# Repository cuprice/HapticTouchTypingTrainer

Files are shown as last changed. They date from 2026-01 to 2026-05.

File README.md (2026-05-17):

## タイピング練習用キーボード基板 Haptic Touch Typing Trainer (Prototype)

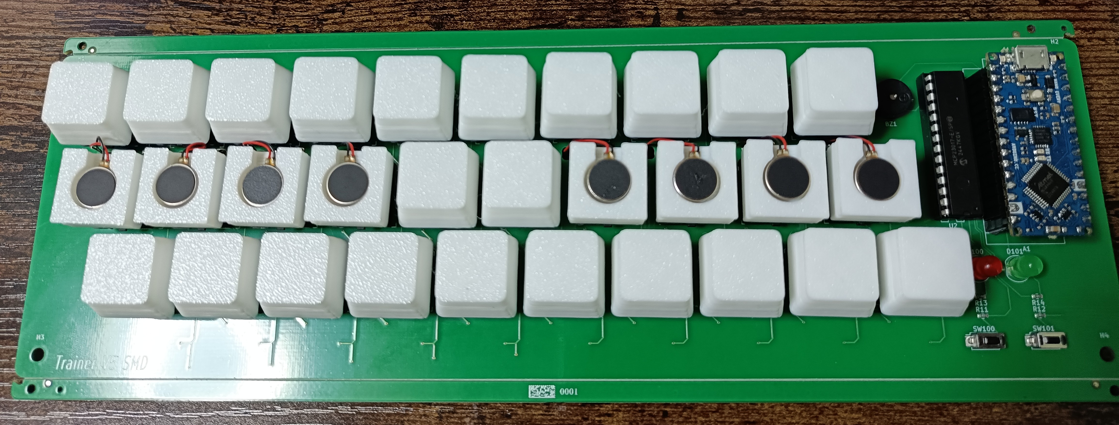
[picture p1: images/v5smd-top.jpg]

基板写真

# これは何？
What is this?

A haptic and audio-guided touch typing trainer that tells you which key to press next through vibration and sound — no need to look at your hands.

振動と音で次に押すべきキーを知らせる、触覚と聴覚を使ったタッチタイピング練習機です。

# はじめに

このリポジトリは回路・プログラミング初学者の学習用です。あたたかく見守っていただけると嬉しいです。

これは、プログラミングや回路の初心者である私が、自分なりに学びながら作ってみた実装基板です。  
8つのキーに振動する部品を付け、目で確認しなくてもどこを押せば良いかがわかる機能を目指しました。
~~公開しようと思ったきっかけは、似たようなアイデアのタイピング練習機を見つけることができなかったためです。~~

触覚を利用した複雑なタッチタイピングの練習機械が他にもあることを知り、私はまだまだ勉強不足であると思いました。もしお嫌でなければ、学習の活動を見守っていただければ幸いです。

このリポジトリでは、タイピング練習を目的としたキーボード基板の設計データを公開しています。  
基板はKiCad 9.0で設計されています。振動するキー順番を変更するには、Arduinoのスケッチを編集する必要があります。

ただし、現在はアイデア段階であり、完全な完成品ではありません。今後の改善や追加機能に関しては更新を行う予定です。

This repository is for beginners who are learning circuits and programming.
I’d be happy if you could kindly support it.

This is a keyboard I made while learning programming and circuits by myself.
I am still a beginner, but I tried my best to build it.

I added small parts that can vibrate to 8 keys.
This way, you can feel which key to press without looking.

~~I decided to share this because I couldn't find a similar typing practice device online.~~

I learned that there are other machines that use touch to practice touch typing in a complex way, and I felt that I still have a lot to learn.
If you don’t mind, I would be happy if you could watch over my learning.

In this repository, I show the design data for this keyboard.
I made the design using KiCad 9.0.
If you want to change the order of the vibrating keys, you need to change the Arduino program.

Please note that this is still just an idea, not a finished product.
I want to improve it and add more features in the future.

---

## 特徴

- 10列、3段のキー(計30個)による練習用構成
- リセットスイッチ付き
- Cherry MX対応
- Arduino Nano Everyで完璧ではありませんが、一応動作確認済みです (後継機のモデルは動作未確認)
- KiCad 9.0で基板設計
- 基板サイズ：約261.1mm × 81.5mm(捨て基板除く)
- 電源：Arduino Nano Every経由でのUSB給電

This is a practice keyboard layout with 30 keys, arranged in 10 columns and 3 rows.
It includes a reset switch. It's compatible with Cherry MX switches. I've confirmed it works with the Arduino nano every, although it's not perfect. I haven't tested it with newer Arduino models. The circuit board was designed using KiCad 9.0. The board size is about 261.1mm × 81.5mm, and it's powered by USB through the Arduino nano every.

どの段のキーを押せば良いかを、3段階のブザー音で教えるためのコードを加筆修正しました。上の段ならば3回鳴り、下の段ならば１回鳴り、真ん中の段なら２回鳴るという仕組みにしました。振動モーターがないキーの場合は、振動する長さを変えて位置を知らせるようにしました。

I changed the code to use three kinds of buzzer sounds to tell the user which row of keys to press.
If the key is on the top row, the buzzer beeps three times.
If the key is on the bottom row, it beeps one time.
If the key is on the middle row, it beeps two times.
For keys that do not have a vibration motor, the device changes the length of the vibration to show the position.

---

## ファイル構成

~~~

TypingTrainer/
    ├── TYPING-TRAINER-V5-SMD/ # KiCad設計ファイル
    ├── TYPING-TRAINER-V5-SMD.zip # ガーバーデータ（基板製造用）
    ├── TrainerV5-smd/ # Arduinoスケッチ 通常版
    ├── TrainerV5-smd2/ # Arduinoスケッチ 切替式例文プリセットタイプ
    ├── numorder.py # キーの順番を決めるPythonスクリプト
    ├── keycap.stl # 3Dプリンタ用、穴有りキャップ
    ├── images/ # 写真・完成図
    ├── docs/ # 部品表・座標データなど
    ├── OldVersion-Uno # 旧バージョン、Uno用
    ├── OldVersion-Nano # 旧バージョン、Nano用
    └── README.md # このファイル

~~~

---

## 完成イメージ、回路図、動作の様子

基板写真

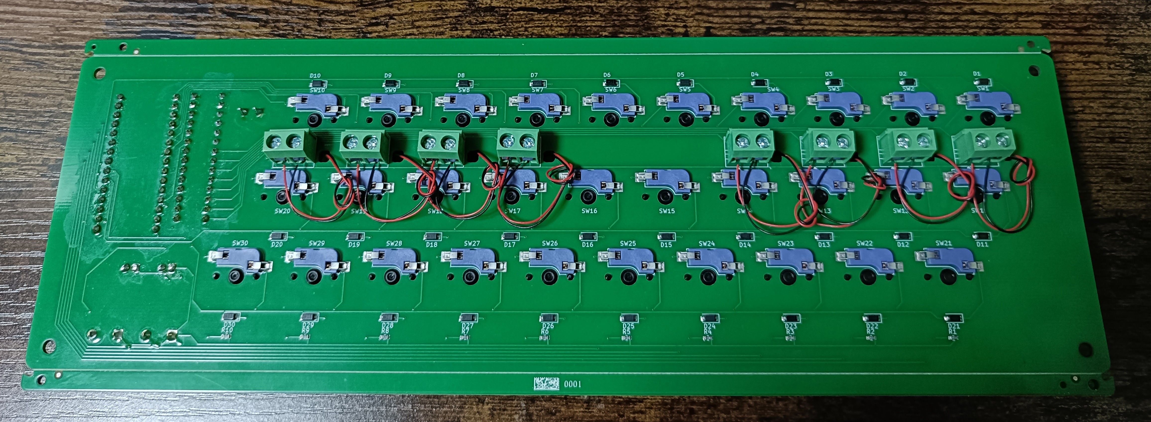
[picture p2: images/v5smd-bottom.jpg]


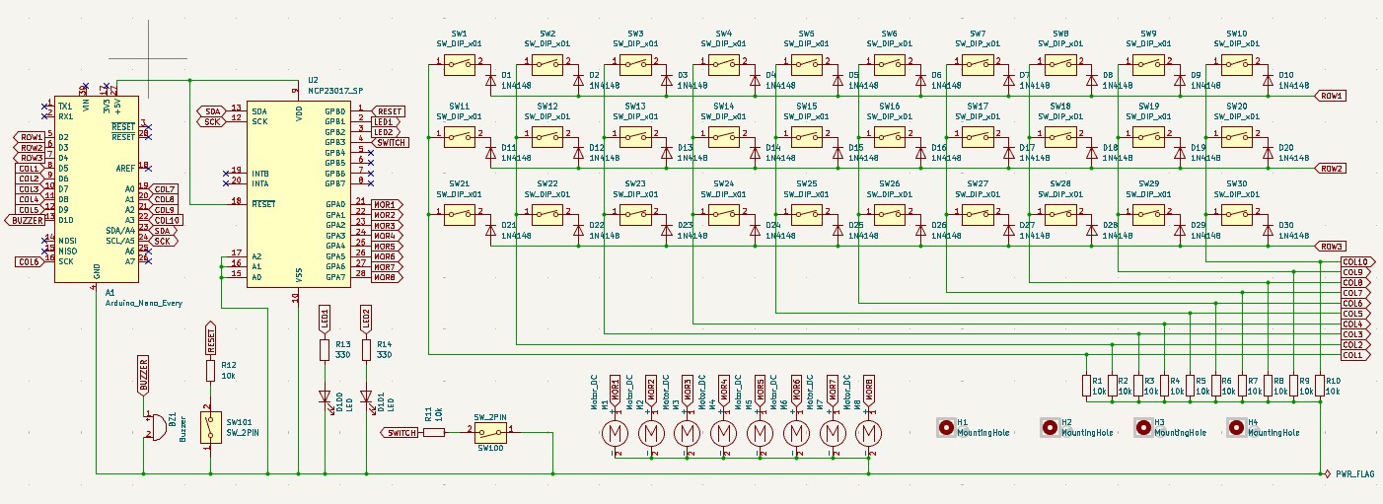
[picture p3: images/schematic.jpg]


[動作の様子](images/working.mp4)

[モーターの動き](images/shaker.mp4)

---

## 使い方
1. ガーバーファイルをJLCPCBなどで製造依頼
2. 回路図などを見ながら部品を実装
3. Arduino Nano EveryをUSBケーブルでPCと接続
4. PCからArduinoへ、ファームウェアを書き込み

---

## 必要部品

| Value | Reference | Qty | 備考 | 画像 |
|---|---|-----|---|---|
| Arduino Nano Every  | A1 | 1 | マイクロコントローラー（ソケットピン経由で実装） |  |
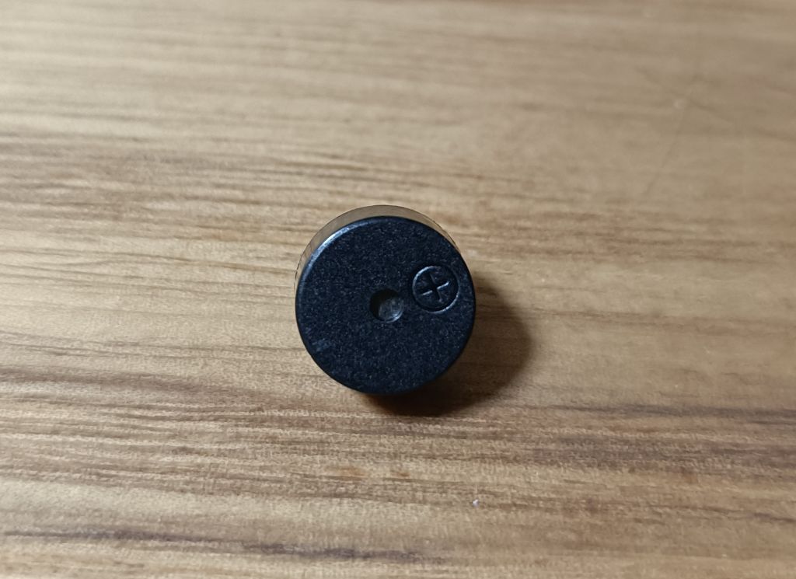
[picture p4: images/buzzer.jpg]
| Passive Buzzer | BZ1 | 1 | パッシブブザー |  |
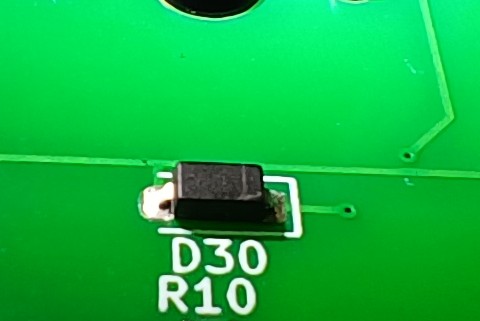
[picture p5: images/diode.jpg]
| 1N4148 | D1 〜 D30 | 30  | スイッチのマトリックス用ダイオード |  |
| LED | D100, D101 | 2 | インジケーターLED |  |
| Motor DC | M1 〜 M8 | 8 | DCモーター |  |
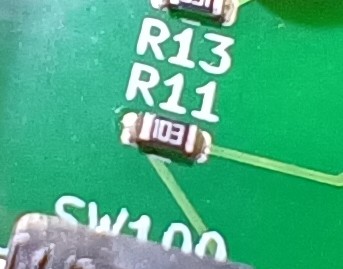
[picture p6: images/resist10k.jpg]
| Resist 10k | R1 〜 R12 | 12  | 抵抗（10kΩ） |  |
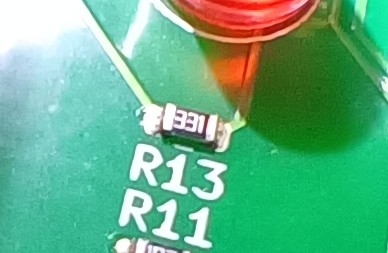
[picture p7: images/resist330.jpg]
| Resist 330 | R13, R14 | 2 | 抵抗（330Ω, LED電流制限用） |  |
| Cherry MX Switch | SW1 〜 SW30 | 30  | Cherry MX互換キースイッチ(キーキャップはお好みで) |  |
| 2pin Button | SW100, SW101 | 2 | 2ピンのタクトスイッチなど |  |
| MCP23017_SP | U2 | 1 | I/Oエキスパンダー（ICソケットの上に実装） |  |
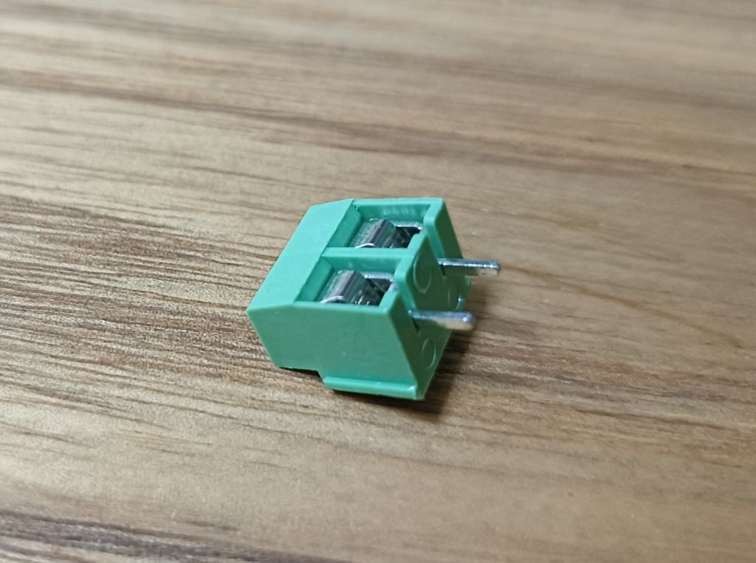
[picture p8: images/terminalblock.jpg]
| TerminalBlock | M1 〜 M8 | 8 | ターミナルブロック(裏面実装) |  |
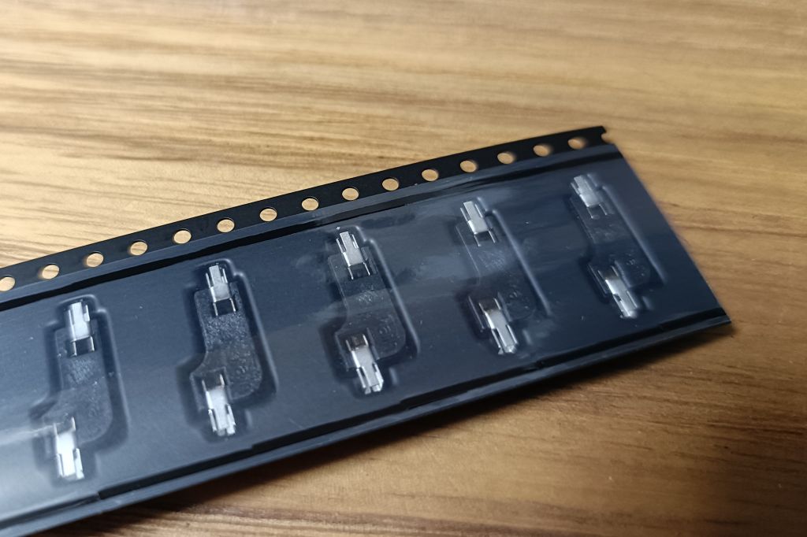
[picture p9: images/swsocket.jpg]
| SW socket | SW1 〜 SW30 | 30 | キースイッチソケット(裏面実装) |  |

---

## KiCad情報

- KiCad バージョン: 9.0
- 古いバージョンでは一部ファイルが開けない可能性があります。
- 最新バージョンでの動作は未確認です。

使用したライブラリURL
- ブザーフットプリント
 https://jp.sameskydevices.com/product/resource/pcbfootprint/cmt-9648-85t
- キースイッチフットプリント
 https://github.com/daprice/keyswitches.pretty?tab=readme-ov-file

---

## ライセンス

この基板デザインは MIT ライセンスで公開しています。  

---

## よくある質問

準備中
**Q. ？**  
A. 

---

## 注意事項

- 初心者が学びながら作ったものなので、不完全な点もあるかもしれません。
- Arduinoスケッチの一部のコード作成に、生成AI（ChatGPT）を補助的に活用しました。

---

## Special Thanks

- ネット上のチュートリアルや電子工作記事の皆さま

---

# 今後の予定
- キーを押す順番の配列を簡単に作るツール
- 製作手順のガイドを作る

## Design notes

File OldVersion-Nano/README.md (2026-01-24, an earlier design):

## タイピング練習用キーボード基板 Typing Haptic Trainer (Prototype)

基板写真
キーキャップ

2026.1.24
3Dプリンターを購入して、試しに特定のキーだけキーキャップをはめ込み式に変えました。あと、この先の予定としては、ダイオードや抵抗を表面実装に変更したものを作るつもりです。

I bought a 3D printer and tried changing only some keycaps to a snap-on type.
Next, I plan to make a version with surface-mounted diodes and resistors.

2025.11.25
Githubに公開してから数ヶ月経ちました。それ以来、触覚を利用したタッチタイピングの練習機械が他にもあることを知り、私のウェブ検索が十分でなかったと申し訳なく思いました。他の人々の作る機械はとても複雑でレベルの高いことも知り、私はまだまだ勉強不足であると思いました。もしお嫌でなければ、学習の活動を見守っていただければ幸いです。

I published my project on GitHub a few months ago.
After that, I learned that there are other typing training devices that use touch.
I felt sorry because my web search was not good enough.
I also found that other people’s devices are very complex and high-level, and I realized that I still have a lot to learn. If you don’t mind, I would be happy if you could watch my learning journey.

2025.11.23
基板を新しくしました！作った基板にArduino Nano Everyを組み込みました。
I made a new PCB and installed an Arduino Nano Every on it.

このリポジトリは回路・プログラミング初学者の学習用です。あたたかく見守っていただけると嬉しいです。

これは、プログラミングや回路の初心者である私が、自分なりに学びながら作ってみた実装基板です。  
8つのキーに振動する部品を付け、目で確認しなくてもどこを押せば良いかがわかる機能を目指しました。
公開しようと思ったきっかけは、似たようなアイデアのタイピング練習機を見つけることができなかったためです。

このリポジトリでは、タイピング練習を目的としたキーボード基板の設計データを公開しています。  
基板はKiCad 9.0で設計されています。振動するキー順番を変更するには、Arduinoのスケッチを編集する必要があります。

ただし、現在はアイデア段階であり、完全な完成品ではありません。今後の改善や追加機能に関しては更新を行う予定です。

This repository is for beginners who are learning circuits and programming.
I’d be happy if you could kindly support it.

This is a keyboard I made while learning programming and circuits by myself.
I am still a beginner, but I tried my best to build it.

I added small parts that can vibrate to 8 keys.
This way, you can feel which key to press without looking.

I decided to share this because I couldn't find a similar typing practice device online.

In this repository, I show the design data for this keyboard.
I made the design using KiCad 9.0.
If you want to change the order of the vibrating keys, you need to change the Arduino program.

Please note that this is still just an idea, not a finished product.
I want to improve it and add more features in the future.

---

## 特徴

- 10列、3段のキー(計30個)による練習用構成
- リセットスイッチ付き
- Cherry MX対応
- Arduino nano everyで完璧ではありませんが、一応動作確認済みです (後継機のモデルは動作未確認)
- KiCad 9.0で基板設計
- 基板サイズ：約261.1mm × 81.5mm
- 電源：Arduino nano every経由でのUSB給電

This is a practice keyboard layout with 30 keys, arranged in 10 columns and 3 rows.
It includes a reset switch. It's compatible with Cherry MX switches. I've confirmed it works with the Arduino nano every, although it's not perfect. I haven't tested it with newer Arduino models. The circuit board was designed using KiCad 9.0. The board size is about 261.1mm × 81.5mm, and it's powered by USB through the Arduino nano every.

どの段のキーを押せば良いかを、3段階のブザー音で教えるためのコードを加筆修正しました。上の段ならば3回鳴り、下の段ならば１回鳴り、真ん中の段なら２回鳴るという仕組みにしました。振動モーターがないキーの場合は、振動する長さを変えて位置を知らせるようにしました。

I changed the code to use three kinds of buzzer sounds to tell the user which row of keys to press.
If the key is on the top row, the buzzer beeps three times.
If the key is on the bottom row, it beeps one time.
If the key is on the middle row, it beeps two times.
For keys that do not have a vibration motor, the device changes the length of the vibration to show the position.

---

## ファイル構成

~~~

TypingTrainer/
    ├── TYPING-TRAINER-V5-2025-10-13_115341/ # KiCad設計ファイル
    ├── TYPING-TRAINER-V5.1.zip # ガーバーデータ（基板製造用）
    ├── TrainerV5active/ # Arduinoスケッチ
    ├── images/ # 写真・完成図
    ├── docs/ # 部品表
    └── README.md # このファイル

~~~

---

## 完成イメージ、回路図、動作の様子

基板写真

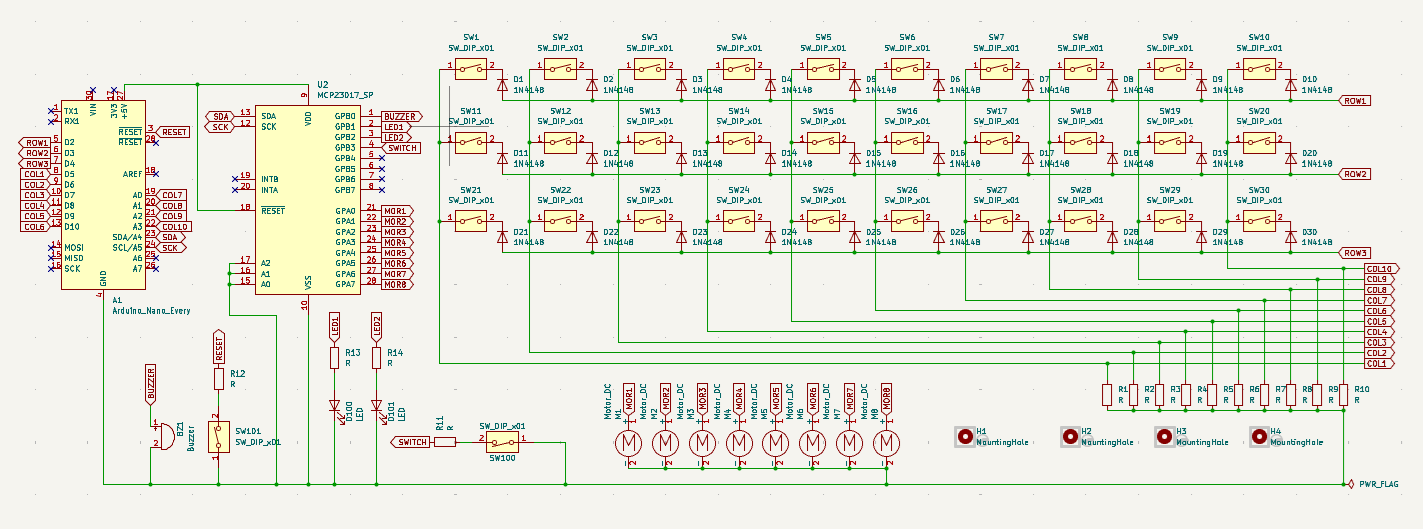
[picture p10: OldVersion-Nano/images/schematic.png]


[動作の様子](images/working.mp4)

[モーターの動き](images/shaker.mp4)

---

## 使い方
1. ガーバーファイルをPCBwayなどで製造依頼
2. 回路図などを見ながら部品を実装
3. Arduino nano everyをUSBケーブルでPCと接続
4. PCからArduinoへ、ファームウェアを書き込み

---

## 必要部品

| Value | Reference | Qty | 備考 | 画像 |
|---|---|-----|---|---|
| Arduino Nano Every  | A1 | 1 | マイクロコントローラー（ソケットピン経由で実装） |  |
| Buzzer | BZ1 | 1 | ブザー |  |
| 1N4148 | D1 〜 D30 | 30  | スイッチのマトリックス用ダイオード |  |
| LED | D100, D101 | 2 | インジケーターLED |  |
| Motor DC | M1 〜 M8 | 8 | DCモーター |  |
| 10k | R1 〜 R12 | 12  | 抵抗（10kΩ） |  |
| 330 | R13, R14 | 2 | 抵抗（330Ω, LED電流制限用） |  |
| Cherry MX Switch | SW1 〜 SW30 | 30  | Cherry MX互換キースイッチ(キーキャップはお好みで) |  |
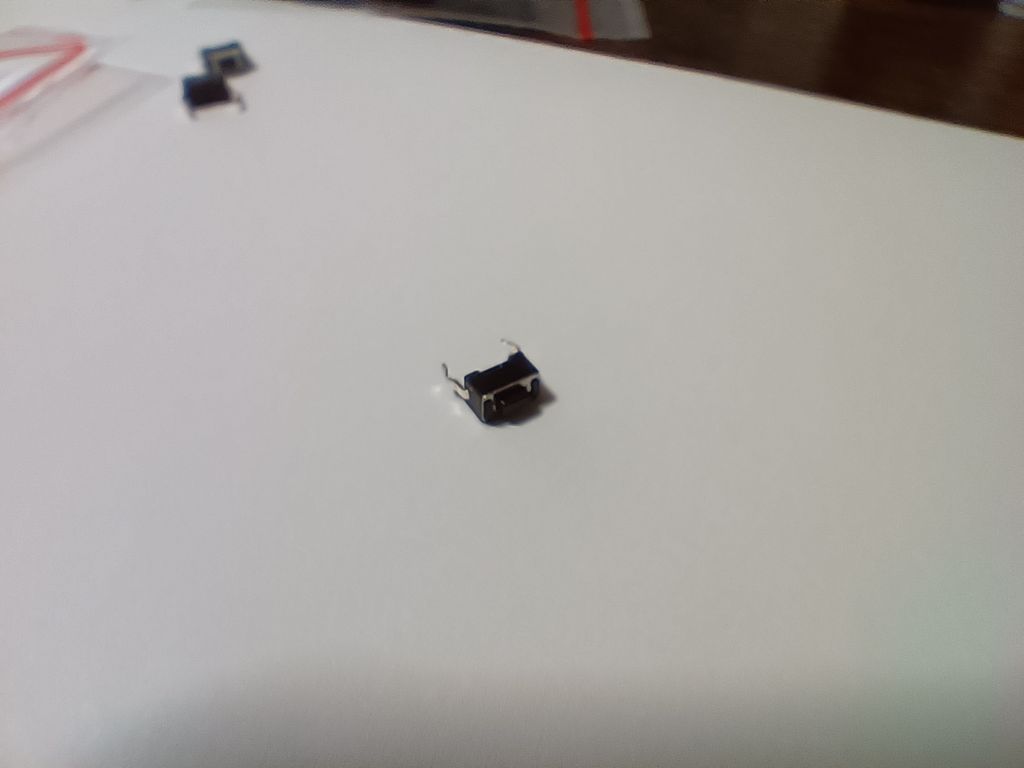
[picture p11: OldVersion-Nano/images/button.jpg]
| 2pin Button | SW100, SW101 | 2 | 2ピンのタクトスイッチなど |  |
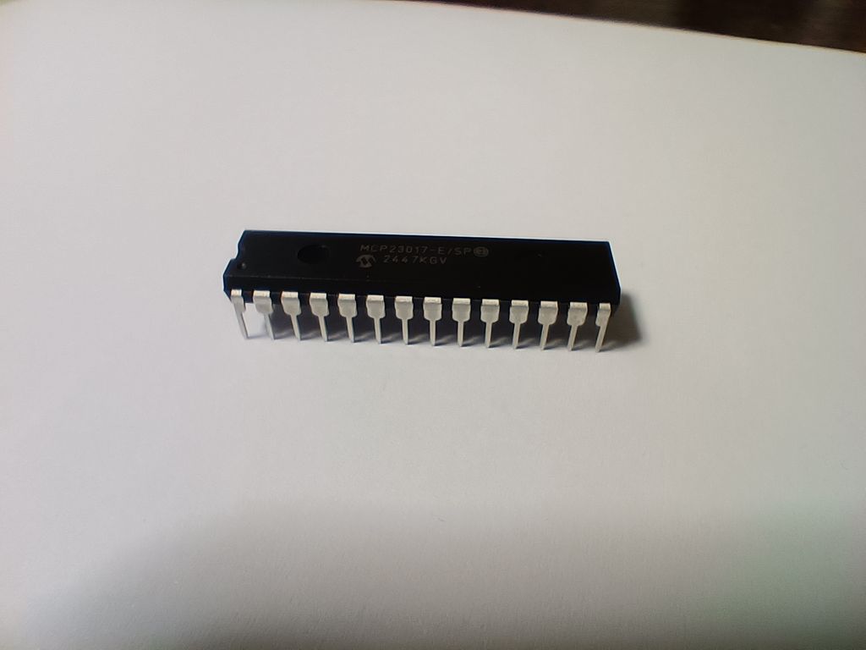
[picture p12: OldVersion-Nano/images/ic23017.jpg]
| MCP23017_SP | U2 | 1 | I/Oエキスパンダー（ICソケットの上に実装） |  |

---

## KiCad情報

- KiCad バージョン: 9.0
- 古いバージョンでは一部ファイルが開けない可能性があります。
- 最新バージョンでの動作は未確認です。

---

## ライセンス

この基板デザインは MIT ライセンスで公開しています。  

---

## よくある質問

準備中
**Q. ？**  
A. 

---

## 注意事項

- 初心者が学びながら作ったものなので、不完全な点もあるかもしれません。
- Arduinoスケッチの一部のコード作成に、生成AI（ChatGPT）を補助的に活用しました。

---

## Special Thanks

- ネット上のチュートリアルや電子工作記事の皆さま

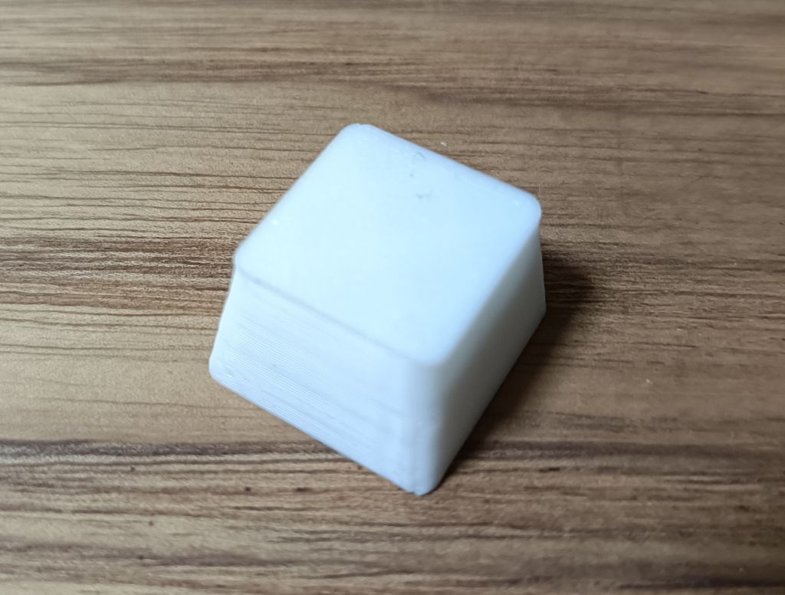
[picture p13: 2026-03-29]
images/keycap.jpg

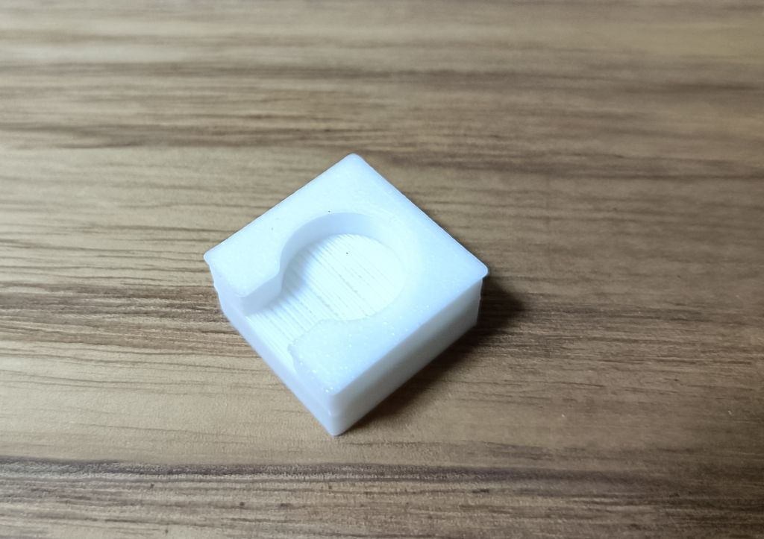
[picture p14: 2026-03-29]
images/keycap-holetype.jpg

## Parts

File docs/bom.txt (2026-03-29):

Value	                Reference	Qty	備考
Arduino Nano Every	A1	        1	マイクロコントローラー
Buzzer	                BZ1	        1	ブザー
1N4148	                D1 〜 D30	30	スイッチのマトリックス用ダイオード
LED	                D100, D101	2	インジケーターLED
TerminalBlock       M1 〜 M8	8	ターミナルブロック5mmピッチ
Motor               M1 〜 M8    8   DCDCモーター
10k	                R1 〜 R12	12	抵抗 (10kΩ)
330	                R13, R14	2	抵抗 (330Ω, LED電流制限用)
Cherry mx switch	SW1 〜 SW30	30	Cherry MX互換キースイッチ
Switch Socket   	SW1 〜 SW30	30	Cherry MX互換キーソケット
2pin button	        SW100, SW101	2	2ピンのタクトスイッチなど
MCP23017_SP	        U2	        1	I/Oエキスパンダー

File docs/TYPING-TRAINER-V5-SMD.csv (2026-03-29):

Reference | Value | Footprint | Qty | LCSC
D1,D2,D3,D4,D5,D6,D7,D8,D9,D10,D11,D12,D13,D14,D15,D16,D17,D18,D19,D20,D21,D22,D23,D24,D25,D26,D27,D28,D29,D30 | 1N4148 | Diode_SMD:D_SOD-123 | 30 | C2099
R1,R2,R3,R4,R5,R6,R7,R8,R9,R10,R11,R12 | 10k | Resistor_SMD:R_0603_1608Metric | 12 | C99198
R13,R14 | 330 | Resistor_SMD:R_0603_1608Metric | 2 | C105879
SW1,SW2,SW3,SW4,SW5,SW6,SW7,SW8,SW9,SW10,SW11,SW12,SW13,SW14,SW15,SW16,SW17,SW18,SW19,SW20,SW21,SW22,SW23,SW24,SW25,SW26,SW27,SW28,SW29,SW30 | SW_DIP_x01 | Kailh_socket_MX | 30 | C41430893

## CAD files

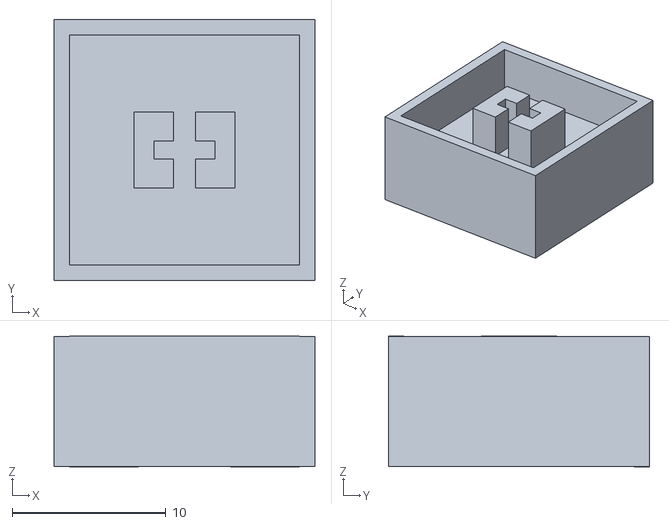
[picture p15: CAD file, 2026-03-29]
keycap.stl
17.0 x 17.0 x 8.50

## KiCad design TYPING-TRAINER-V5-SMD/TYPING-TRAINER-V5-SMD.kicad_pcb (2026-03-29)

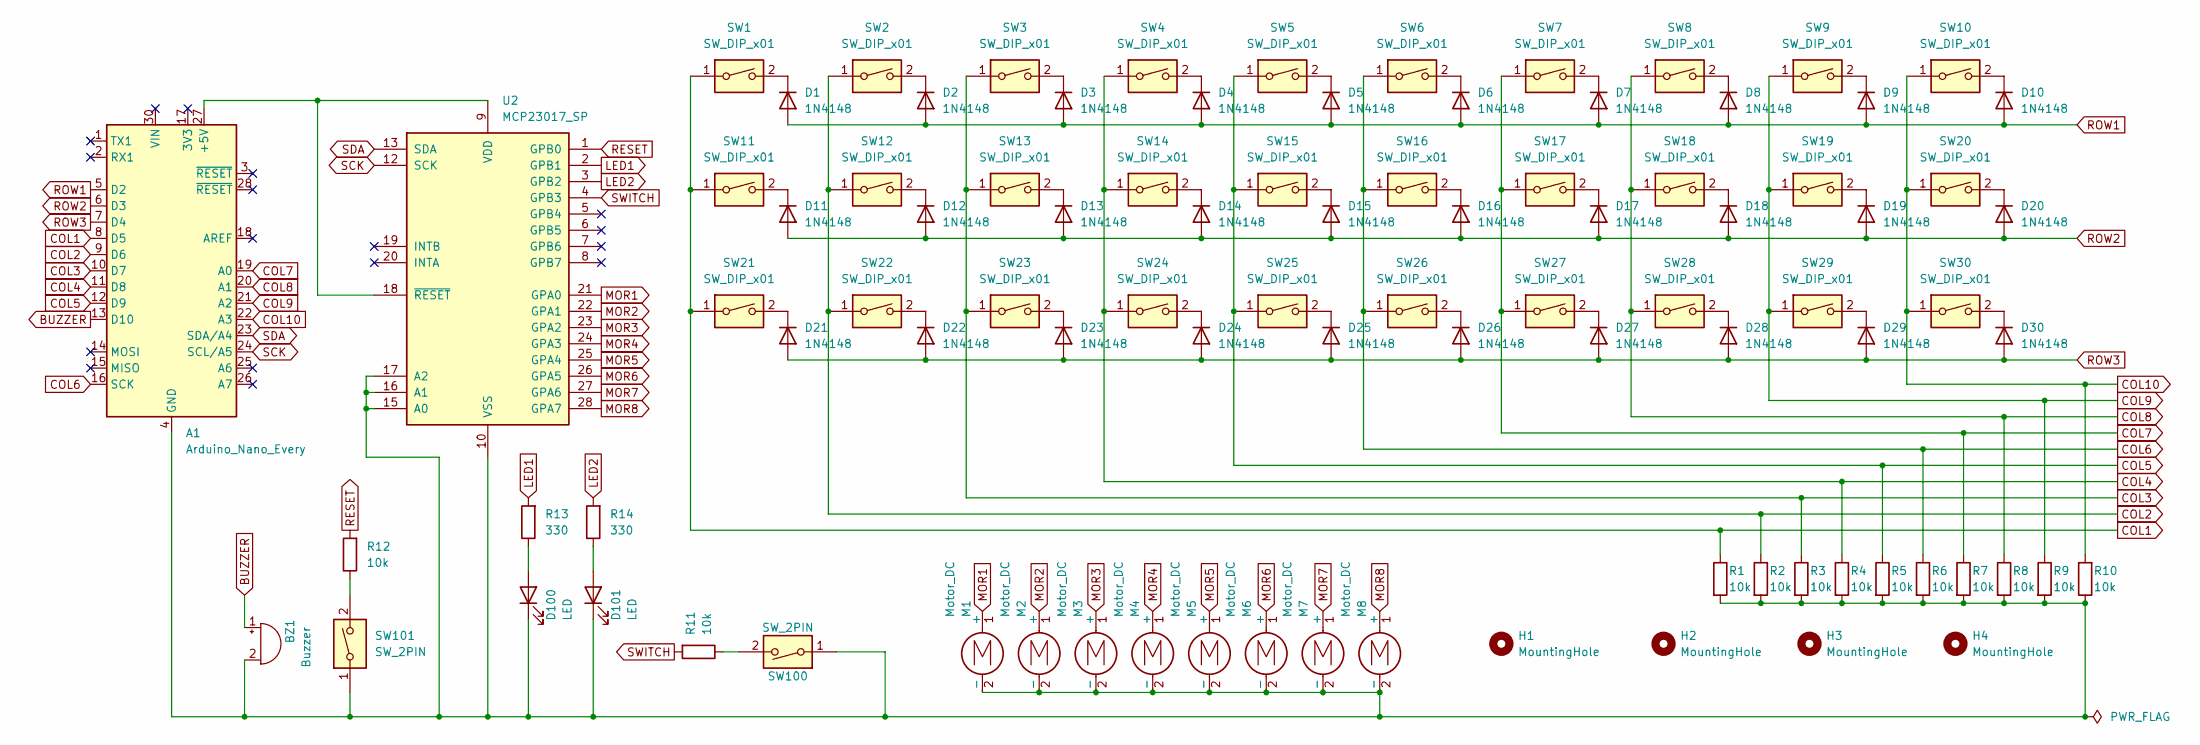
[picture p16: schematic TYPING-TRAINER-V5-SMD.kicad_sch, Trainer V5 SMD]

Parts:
A1: Arduino_Nano_Every; Arduino_Nano
BZ1: Buzzer; XDCR_CMT-9648-85T; LCSC C22359749
D1, D2, D3, D4, D5, D6, D7, D8, D9, D10, D11, D12, D13, D14, D15, D16, D17, D18, D19, D20, D21, D22, D23, D24, D25, D26, D27, D28, D29, D30: 1N4148; D_SOD-123; LCSC C2099
D100, D101: LED; LED_D5.0mm_FlatTop; LCSC C88163
H1, H2, H3, H4: MountingHole; MountingHole_3.2mm_M3
M1, M2, M3, M4, M5, M6, M7, M8: Motor_DC; TerminalBlock_MaiXu_MX126-5.0-02P_1x02_P5.00mm
R1, R2, R3, R4, R5, R6, R7, R8, R9, R10, R11, R12: 10k; R_0603_1608Metric; LCSC C130232
R13, R14: 330; R_0603_1608Metric; LCSC C175652
SW1, SW2, SW3, SW4, SW5, SW6, SW7, SW8, SW9, SW10, SW11, SW12, SW13, SW14, SW15, SW16, SW17, SW18, SW19, SW20, SW21, SW22, SW23, SW24, SW25, SW26, SW27, SW28, SW29, SW30: SW_DIP_x01; Kailh_socket_MX; LCSC C41430893
SW100, SW101: SW_2PIN; SW_PUSH_1P1T_6x3.5mm_H4.3_APEM_MJTP1243
U2: MCP23017_SP; DIP-28_W7.62mm

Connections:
BUZZER: A1.13 (D10), BZ1.1 (+)
COL1: A1.8 (D5), R1.1, SW1.1, SW11.1, SW21.1
COL2: A1.9 (D6), R2.1, SW2.1, SW12.1, SW22.1
COL3: A1.10 (D7), R3.1, SW3.1, SW13.1, SW23.1
COL4: A1.11 (D8), R4.1, SW4.1, SW14.1, SW24.1
COL5: A1.12 (D9), R5.1, SW5.1, SW15.1, SW25.1
COL6: A1.16 (SCK), R6.1, SW6.1, SW16.1, SW26.1
COL7: A1.19 (A0), R7.1, SW7.1, SW17.1, SW27.1
COL8: A1.20 (A1), R8.1, SW8.1, SW18.1, SW28.1
COL9: A1.21 (A2), R9.1, SW9.1, SW19.1, SW29.1
COL10: A1.22 (A3), R10.2, SW10.1, SW20.1, SW30.1
LED1: R13.2, U2.2 (GPB1)
LED2: R14.2, U2.3 (GPB2)
MOR1: M1.1 (+), U2.21 (GPA0)
MOR2: M2.1 (+), U2.22 (GPA1)
MOR3: M3.1 (+), U2.23 (GPA2)
MOR4: M4.1 (+), U2.24 (GPA3)
MOR5: M5.1 (+), U2.25 (GPA4)
MOR6: M6.1 (+), U2.26 (GPA5)
MOR7: M7.1 (+), U2.27 (GPA6)
MOR8: M8.1 (+), U2.28 (GPA7)
unnamed: A1.27 (+5V), U2.9 (VDD), U2.18 (~RESET)
unnamed: A1.4 (GND), A1.29 (GND), BZ1.2 (-), D100.1 (K), D101.1 (K), M1.2 (-), M2.2 (-), M3.2 (-), M4.2 (-), M5.2 (-), M6.2 (-), M7.2 (-), M8.2 (-), R1.2, R2.2, R3.2, R4.2, R5.2, R6.2, R7.2, R8.2, R9.2, R10.1, SW100.1, SW101.1, U2.10 (VSS), U2.15 (A0), U2.16 (A1), U2.17 (A2)
unnamed: D1.1 (K), SW1.2
unnamed: D2.1 (K), SW2.2
unnamed: D3.1 (K), SW3.2
unnamed: D4.1 (K), SW4.2
unnamed: D5.1 (K), SW5.2
unnamed: D6.1 (K), SW6.2
unnamed: D7.1 (K), SW7.2
unnamed: D8.1 (K), SW8.2
unnamed: D9.1 (K), SW9.2
unnamed: D10.1 (K), SW10.2
unnamed: D11.1 (K), SW11.2
unnamed: D12.1 (K), SW12.2
unnamed: D13.1 (K), SW13.2
unnamed: D14.1 (K), SW14.2
unnamed: D15.1 (K), SW15.2
unnamed: D16.1 (K), SW16.2
unnamed: D17.1 (K), SW17.2
unnamed: D18.1 (K), SW18.2
unnamed: D19.1 (K), SW19.2
unnamed: D20.1 (K), SW20.2
unnamed: D21.1 (K), SW21.2
unnamed: D22.1 (K), SW22.2
unnamed: D23.1 (K), SW23.2
unnamed: D24.1 (K), SW24.2
unnamed: D25.1 (K), SW25.2
unnamed: D26.1 (K), SW26.2
unnamed: D27.1 (K), SW27.2
unnamed: D28.1 (K), SW28.2
unnamed: D29.1 (K), SW29.2
unnamed: D30.1 (K), SW30.2
unnamed: D100.2 (A), R13.1
unnamed: D101.2 (A), R14.1
unnamed: R11.1, SW100.2
unnamed: R12.1, SW101.2
RESET: R12.2, U2.1 (GPB0)
ROW1: A1.5 (D2), D1.2 (A), D2.2 (A), D3.2 (A), D4.2 (A), D5.2 (A), D6.2 (A), D7.2 (A), D8.2 (A), D9.2 (A), D10.2 (A)
ROW2: A1.6 (D3), D11.2 (A), D12.2 (A), D13.2 (A), D14.2 (A), D15.2 (A), D16.2 (A), D17.2 (A), D18.2 (A), D19.2 (A), D20.2 (A)
ROW3: A1.7 (D4), D21.2 (A), D22.2 (A), D23.2 (A), D24.2 (A), D25.2 (A), D26.2 (A), D27.2 (A), D28.2 (A), D29.2 (A), D30.2 (A)
SCK: A1.24 (SCL/A5), U2.12 (SCK)
SDA: A1.23 (SDA/A4), U2.13 (SDA)
SWITCH: R11.2, U2.4 (GPB3)

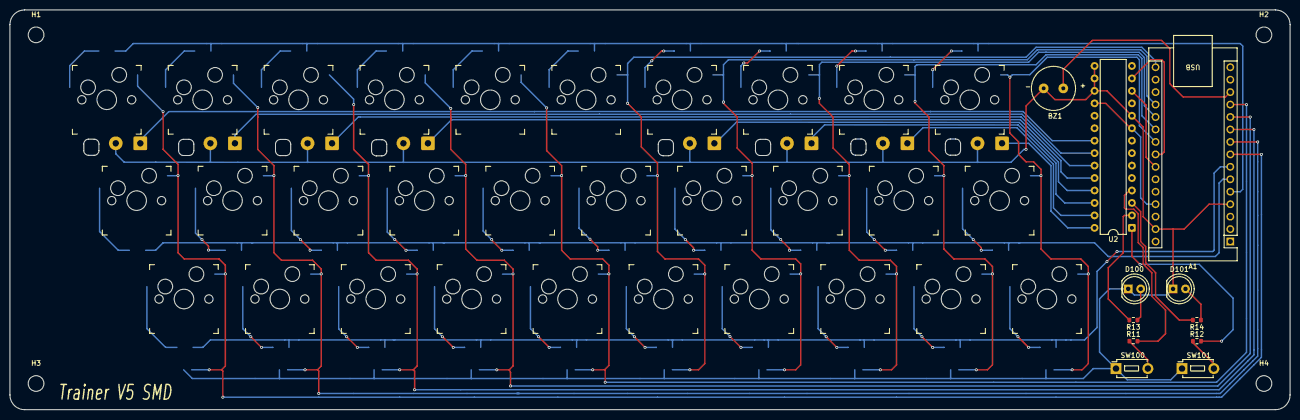
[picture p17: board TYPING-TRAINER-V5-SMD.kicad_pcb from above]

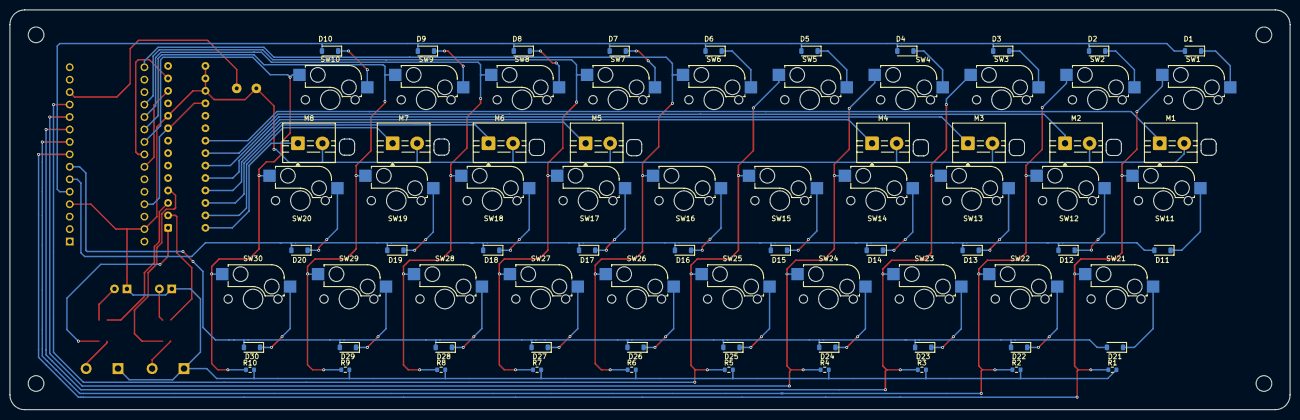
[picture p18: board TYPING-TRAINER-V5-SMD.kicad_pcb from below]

Board: 2 copper layers, 261.1 x 81.5 mm, 93 parts (48 on the bottom side), 64 nets.

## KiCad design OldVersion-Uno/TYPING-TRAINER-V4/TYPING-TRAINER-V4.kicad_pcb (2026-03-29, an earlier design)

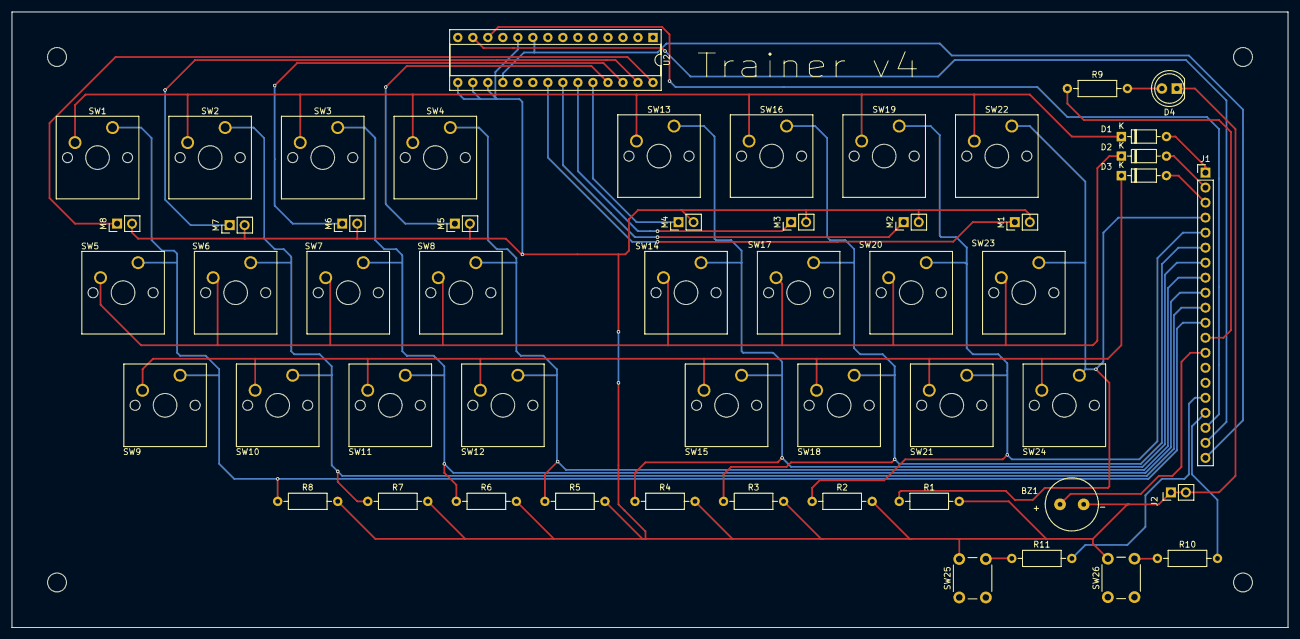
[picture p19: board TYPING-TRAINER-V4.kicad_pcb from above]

Board: 2 copper layers, 215.9 x 104.1 mm, 57 parts (0 on the bottom side), 33 nets.

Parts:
BZ1: Buzzer; XDCR_CMT-9648-85T
D1, D2, D3: 1N4148; D_DO-35_SOD27_P7.62mm_Horizontal
D4: LED; LED_D5.0mm_FlatTop
H1, H2, H3, H4: MountingHole; MountingHole_3.2mm_M3
J1: Conn_01x20_Pin; PinHeader_1x20_P2.54mm_Vertical
J2: Conn_01x02_Pin; PinHeader_1x02_P2.54mm_Vertical
M1, M2, M3, M4, M5, M6, M7, M8: Motor_DC; PinHeader_1x02_P2.54mm_Vertical
R1, R2, R3, R4, R5, R6, R7, R8, R9, R10, R11: R; R_Axial_DIN0207_L6.3mm_D2.5mm_P10.16mm_Horizontal
SW1, SW2, SW3, SW4, SW5, SW6, SW7, SW8, SW9, SW10, SW11, SW12, SW13, SW14, SW15, SW16, SW17, SW18, SW19, SW20, SW21, SW22, SW23, SW24: SW_DIP_x01; SW_Cherry_MX_1.00u_PCB
SW25, SW26: SW_DIP_x02b; SW_PUSH_6mm
U2: MCP23017_SP; CERDIP-28_W7.62mm_SideBrazed_Socket

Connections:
+5V: J1.20, U2.9 (VDD), U2.18 (~RESET)
GND: BZ1.2 (-), D4.1 (K), J2.1, J2.2, M1.2 (-), M2.2 (-), M3.2 (-), M4.2 (-), M5.2 (-), M6.2 (-), M7.2 (-), M8.2 (-), R1.2, R2.2, R3.2, R4.2, R5.2, R6.2, R7.2, R8.2, SW25.1, SW26.1, U2.10 (VSS), U2.15 (A0), U2.16 (A1), U2.17 (A2)
unnamed: BZ1.1 (+), J1.13
unnamed: D1.2 (A), J1.1
unnamed: D1.1 (K), SW1.2, SW2.2, SW3.2, SW4.2, SW13.2, SW16.2, SW19.2, SW22.2
unnamed: D2.2 (A), J1.2
unnamed: D2.1 (K), SW5.2, SW6.2, SW7.2, SW8.2, SW14.2, SW17.2, SW20.2, SW23.2
unnamed: D3.2 (A), J1.3
unnamed: D3.1 (K), SW9.2, SW10.2, SW11.2, SW12.2, SW15.2, SW18.2, SW21.2, SW24.2
unnamed: D4.2 (A), R9.2
unnamed: J1.4, R1.1, SW22.1, SW23.1, SW24.1
unnamed: J1.5, R2.1, SW19.1, SW20.1, SW21.1
unnamed: J1.6, R3.1, SW16.1, SW17.1, SW18.1
unnamed: J1.7, R4.1, SW13.1, SW14.1, SW15.1
unnamed: J1.8, R5.1, SW4.1, SW8.1, SW12.1
unnamed: J1.9, R6.1, SW3.1, SW7.1, SW11.1
unnamed: J1.10, R7.1, SW2.1, SW6.1, SW10.1
unnamed: J1.11, R8.1, SW1.1, SW5.1, SW9.1
unnamed: J1.12, R9.1
unnamed: J1.16, R11.2
unnamed: J1.17, R10.2
unnamed: J1.18, U2.12 (SCK)
unnamed: J1.19, U2.13 (SDA)
unnamed: M1.1 (+), U2.21 (GPA0)
unnamed: M2.1 (+), U2.22 (GPA1)
unnamed: M3.1 (+), U2.23 (GPA2)
unnamed: M4.1 (+), U2.24 (GPA3)
unnamed: M5.1 (+), U2.25 (GPA4)
unnamed: M6.1 (+), U2.26 (GPA5)
unnamed: M7.1 (+), U2.27 (GPA6)
unnamed: M8.1 (+), U2.28 (GPA7)
unnamed: R10.1, SW26.2
unnamed: R11.1, SW25.2

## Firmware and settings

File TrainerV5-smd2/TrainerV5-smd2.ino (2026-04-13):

#include <Adafruit_MCP23X17.h>

Adafruit_MCP23X17 mcp;

const int ROWS = 3;
const int COLS = 10;
const int resetPin = 8;

const int rowPins[ROWS] = {2, 3, 4};
const int colPins[COLS] = {5, 6, 7, 8, 9, 13, 14, 15, 16, 17};

int motorPins[8] = {0, 1, 2, 3, 4, 5, 6, 7};

// ブザー
const int buzzerPin = 10;
const int led = 9;

// ===== タイプ切り替えスイッチ（GPB3）=====
const int typeSwitchPin = 11;
bool lastSwitchState = HIGH;

// ===== 音階 =====
#define DO 262
#define MI 330
#define SO 392
#define LOW_BUZZ 130

// ===== 4タイプ配列 =====
// 赤坂の朝日が坂を上がる光を探す
int motorOrder1[] = {
    0,7,0,1,0,7,0,5,8,0,1,0,5,7,4,0,1,0,7,0,1,8,0,4,0,3,6,5,7,7,0,3,7,1,8,1,0,4,0,1,6
};

int keyRowOrder1[] = {
    1,1,1,1,1,1,1,2,0,1,1,1,1,0,1,1,1,1,1,1,0,0,1,1,1,0,0,1,0,1,1,0,0,0,0,1,1,1,1,1,0
};

// 朝日が差す公園で子どもたちが遊ぶ
int motorOrder2[] = {
    0,1,0,5,7,4,0,1,0,1,6,7,8,6,2,5,2,2,7,8,2,8,6,8,4,0,4,7,4,0,0,1,8,4,6
};

int keyRowOrder2[] = {
    1,1,1,1,0,1,1,1,1,1,0,1,0,0,0,2,1,0,1,0,1,0,2,0,0,1,0,0,1,1,1,1,0,2,0
};

// 魚が川を泳ぎながら水の中で遊ぶ
int motorOrder3[] = {
    1,0,7,0,5,0,4,0,7,0,1,0,1,8,8,5,8,4,7,5,0,4,0,3,0,6,7,0,6,5,8,5,0,7,0,2,2,0,1,8,4,6
};

int keyRowOrder3[] = {
    1,1,1,1,2,1,1,1,1,1,0,1,0,0,0,0,0,1,0,2,1,1,1,0,1,2,0,2,0,2,0,2,1,1,1,1,0,1,1,0,2,0
};

// 今日は天気が良くて公園でゆっくり散歩した
int motorOrder4[] = {
    7,5,8,6,5,0,4,2,5,7,7,4,0,5,8,7,6,4,2,7,8,6,2,5,2,2,5,6,7,7,6,3,7,1,0,5,9,8,1,7,4,0
};

int keyRowOrder4[] = {
    1,0,0,0,1,1,0,0,2,1,0,1,1,0,0,1,0,0,0,1,0,0,0,2,1,0,0,0,1,1,0,0,0,1,1,2,0,0,1,0,0,1
};

// ===== ポインタ管理 =====
int* motorOrder;
int* keyRowOrder;
int TOTAL_SEQUENCE_LENGTH;

// 長さ
int sequenceLengths[] = {18, 20, 22, 27};

int currentType = 0;

int currentMotorPlace = 0;
bool programEnd = false;

// ===== 初期設定 =====
void setType(int type) {
    currentType = type;

    switch (type) {
        case 0:
            motorOrder = motorOrder1;
            keyRowOrder = keyRowOrder1;
            break;
        case 1:
            motorOrder = motorOrder2;
            keyRowOrder = keyRowOrder2;
            break;
        case 2:
            motorOrder = motorOrder3;
            keyRowOrder = keyRowOrder3;
            break;
        case 3:
            motorOrder = motorOrder4;
            keyRowOrder = keyRowOrder4;
            break;
    }

    TOTAL_SEQUENCE_LENGTH = sequenceLengths[type];

    currentMotorPlace = 0;
    programEnd = false;
}

// ===== setup =====
void setup() {
    Serial.begin(9600);
    mcp.begin_I2C(0x20);

    pinMode(buzzerPin, OUTPUT);

    mcp.pinMode(resetPin, INPUT_PULLUP);
    mcp.pinMode(typeSwitchPin, INPUT_PULLUP);

    mcp.pinMode(led, OUTPUT);
    mcp.digitalWrite(led, HIGH);

    for (int i = 0; i < 8; i++) {
        mcp.pinMode(motorPins[i], OUTPUT);
    }

    for (int i = 0; i < ROWS; i++) {
        pinMode(rowPins[i], INPUT_PULLUP);
    }

    for (int j = 0; j < COLS; j++) {
        pinMode(colPins[j], OUTPUT);
        digitalWrite(colPins[j], HIGH);
    }

    // 初期タイプ
    setType(0);
}

// ===== 音関連 =====
void playTone(int freq, int duration) {
    tone(buzzerPin, freq);
    delay(duration);
    noTone(buzzerPin);
    delay(20);
}

void beep(int duration) {
    playTone(DO, duration);
}

void playCorrectSound() {
    playTone(DO, 80);
    playTone(MI, 80);
    playTone(SO, 120);
}

void playErrorSound() {
    tone(buzzerPin, LOW_BUZZ);
    delay(400);
    noTone(buzzerPin);
    delay(50);
}

void multipleBeeps(int count) {
    for (int k = 0; k < count; k++) {
        beep(100);
    }
}

// ===== モーター変換 =====
int getMotorPinIndex(int expectedCol) {
    if (expectedCol >= 0 && expectedCol <= 3) {
        return expectedCol;
    } else if (expectedCol >= 6 && expectedCol <= 9) {
        return expectedCol - 2;
    } else if (expectedCol == 4) {
        return 3;
    } else if (expectedCol == 5) {
        return 4;
    }
    return -1;
}

// ===== loop =====
void loop() {

    // ===== タイプ切り替え =====
    bool currentSwitchState = mcp.digitalRead(typeSwitchPin);

    if (lastSwitchState == HIGH && currentSwitchState == LOW) {

        currentType++;
        if (currentType >= 4) currentType = 0;

        setType(currentType);

        beep(150); // 切替音
        delay(300);
    }

    lastSwitchState = currentSwitchState;

    // ===== リセット =====
    if (mcp.digitalRead(resetPin) == LOW) {
        currentMotorPlace = 0;
        programEnd = false;
        playErrorSound();
        delay(300);
        return;
    }

    if (programEnd) return;

    int expectedCol = motorOrder[currentMotorPlace];
    int expectedRow = keyRowOrder[currentMotorPlace];

    int motorIndex = getMotorPinIndex(expectedCol);

    // 段通知
    switch (expectedRow) {
        case 0: multipleBeeps(3); break;
        case 1: multipleBeeps(2); break;
        case 2: multipleBeeps(1); break;
    }

    // モーター
    if (motorIndex != -1) {
        if (expectedCol == 4 || expectedCol == 5) {
            mcp.digitalWrite(motorPins[motorIndex], HIGH);
            delay(300);
            mcp.digitalWrite(motorPins[motorIndex], LOW);
            delay(300);
            mcp.digitalWrite(motorPins[motorIndex], HIGH);
            delay(300);
        } else {
            mcp.digitalWrite(motorPins[motorIndex], HIGH);
            delay(200);
            mcp.digitalWrite(motorPins[motorIndex], LOW);
            delay(200);
        }
    }

    // キースキャン
    for (int j = 0; j < COLS; j++) {
        digitalWrite(colPins[j], LOW);

        for (int i = 0; i < ROWS; i++) {
            if (digitalRead(rowPins[i]) == LOW) {

                if (i == expectedRow && j == expectedCol) {
                    currentMotorPlace++;

                    playCorrectSound();

                    if (currentMotorPlace >= TOTAL_SEQUENCE_LENGTH) {
                        programEnd = true;

                        playCorrectSound();
                        delay(200);
                        playCorrectSound();

                        mcp.digitalWrite(led, LOW);
                    }

                    digitalWrite(colPins[j], HIGH);
                    return;
                } else {
                    playErrorSound();
                }
            }
        }
        digitalWrite(colPins[j], HIGH);
    }
}
